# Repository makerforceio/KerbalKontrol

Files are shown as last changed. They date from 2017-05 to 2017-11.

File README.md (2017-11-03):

# KerbalKontrol
Kerbal Space Program is a popular space simulator game which we at MakerForce been enjoying for a while. So, we decided
to just go build an arcade like console for it. This project was fortunate enough to be featured on [Hackaday](), and you
can check out the original blog post [here](https://makerforce.io/the-ksp-command-station-2/).

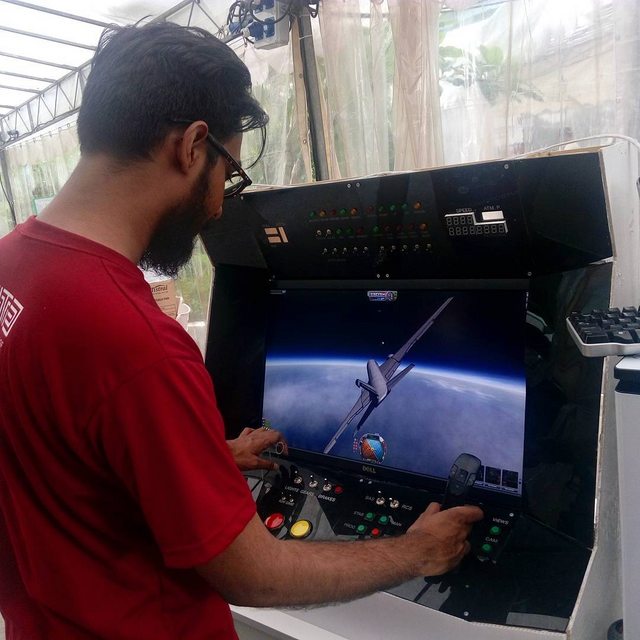
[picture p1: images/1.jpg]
KerbalKontrol station


# Implementation
This control station is based fully upon the ATMEGA328 as its primary MCU. It is powered by 2 custom designed PCBs - the IO-Board and the Main-Board. The IO-Board is connected to each panel and contains a single MCU + shift registers. All of the IO-Boards are wired to the Main-Board using RJ45 conns and ethernet cables. The communication bus within is currently I2C but we want to switch to D-I2C in the future. All of the IO-Boards are configured as I2C Slaves and the Main-Board is the single master.

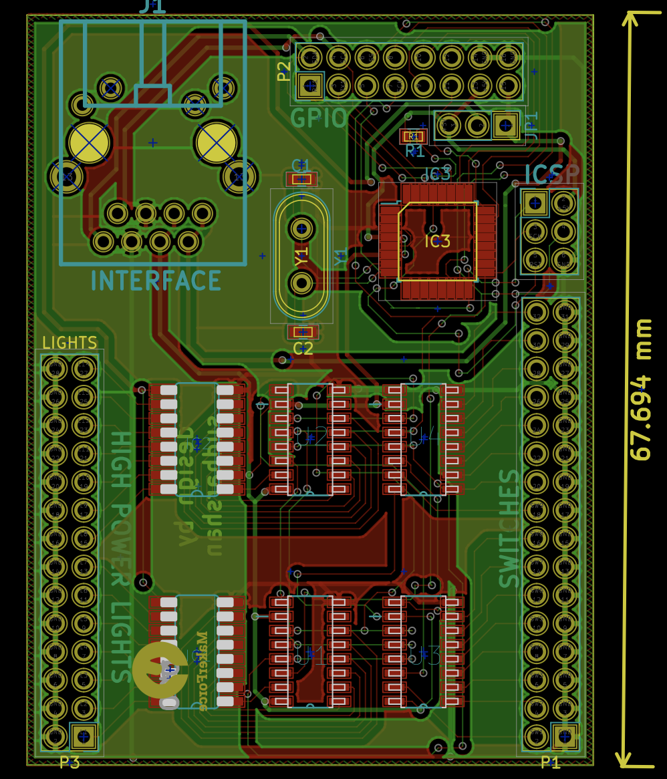
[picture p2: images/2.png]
IO-Board


The internal switches, lights are wired up to the boards through the header connectors visible on the IO-Board.

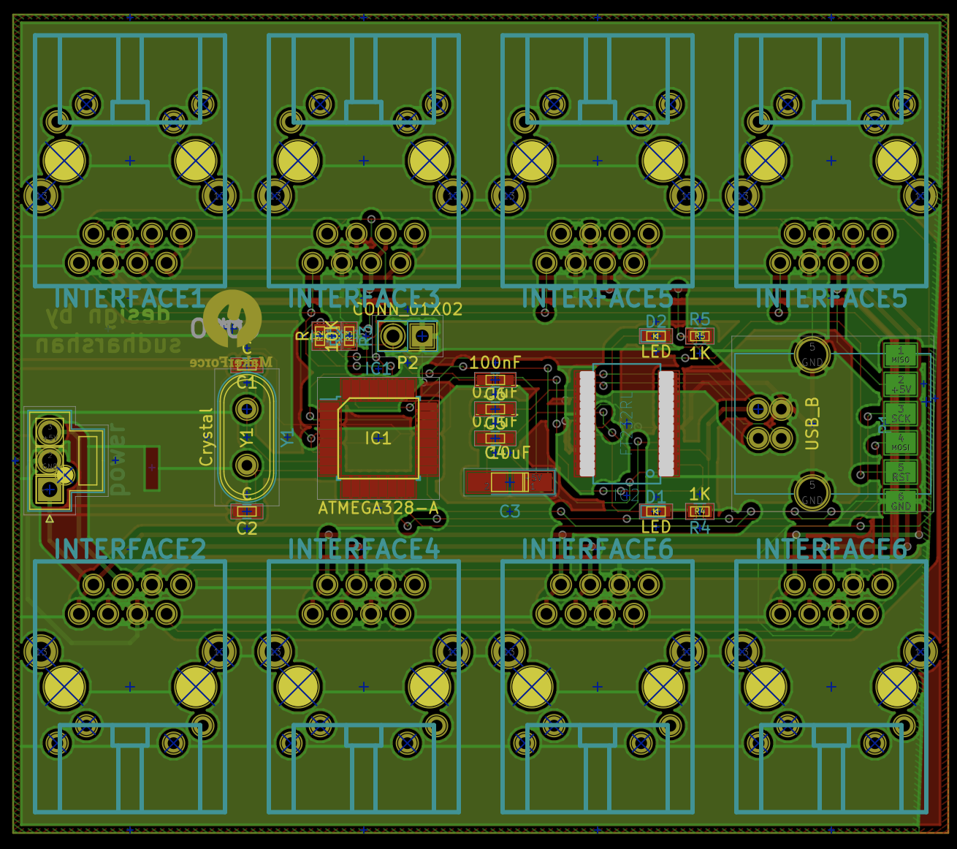
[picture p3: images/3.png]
Main-Board


# Software
Everything is programmed using avr-libc with no external libraries. 

## Compile from source
To compile from source for the IO-Board and Main-Board, follow the steps below.

```
git clone https://www.github.com/solderneer/KerbalKontrol
cd code/io-board
make
```

```
git clone https://www.github.com/solderneer/KerbalKontrol
cd code/main-board
make
```
The directory can simply be cleaned with this command.

```
make clean
```

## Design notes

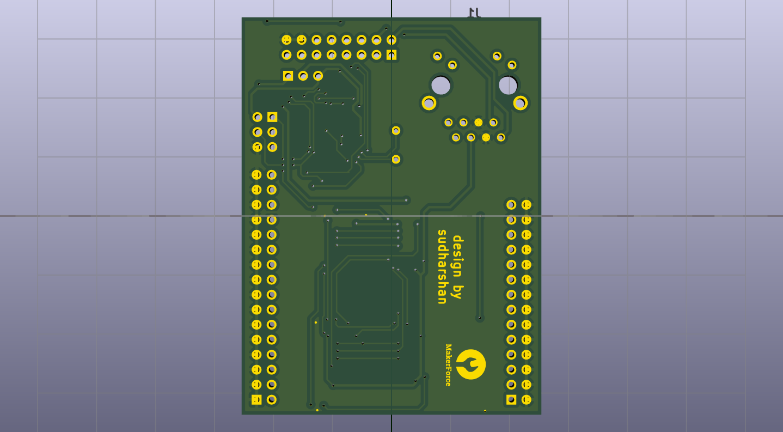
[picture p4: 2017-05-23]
electronics/renders/io-board.back.png

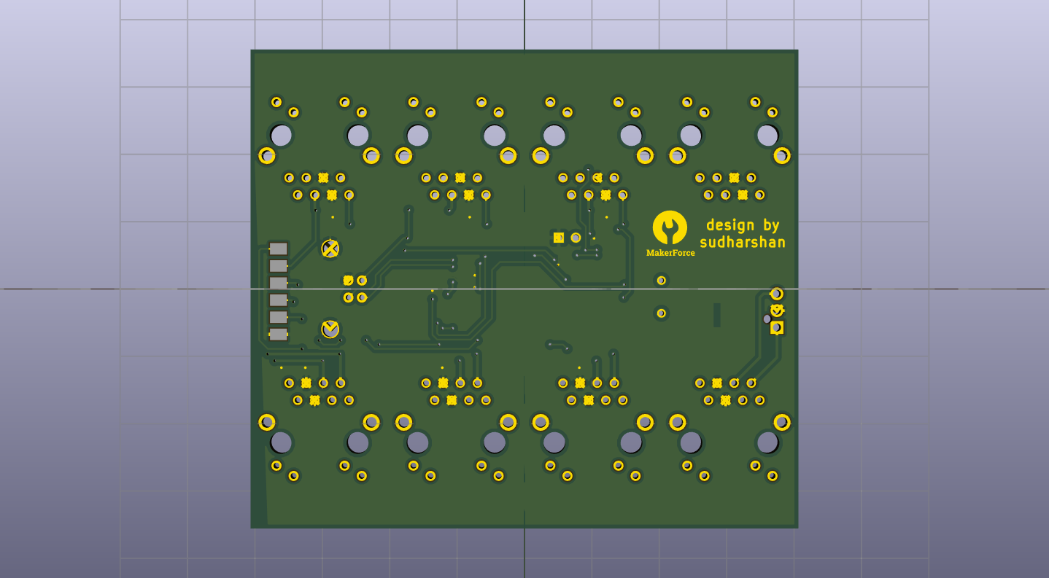
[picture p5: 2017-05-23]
electronics/renders/main-board.back.png

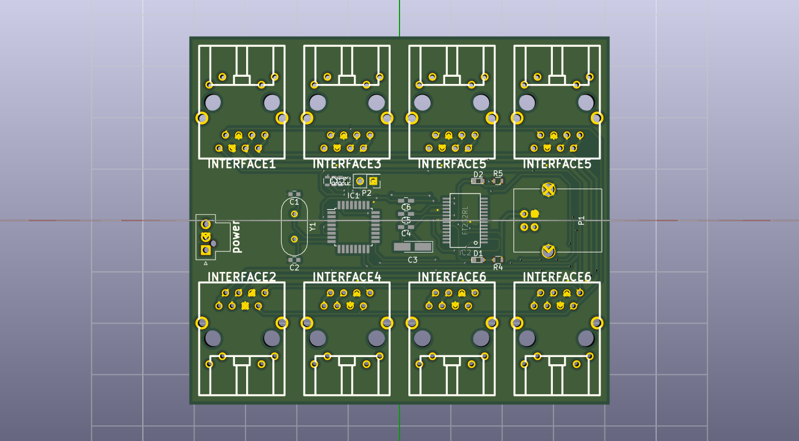
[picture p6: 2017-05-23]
electronics/renders/main-board.png

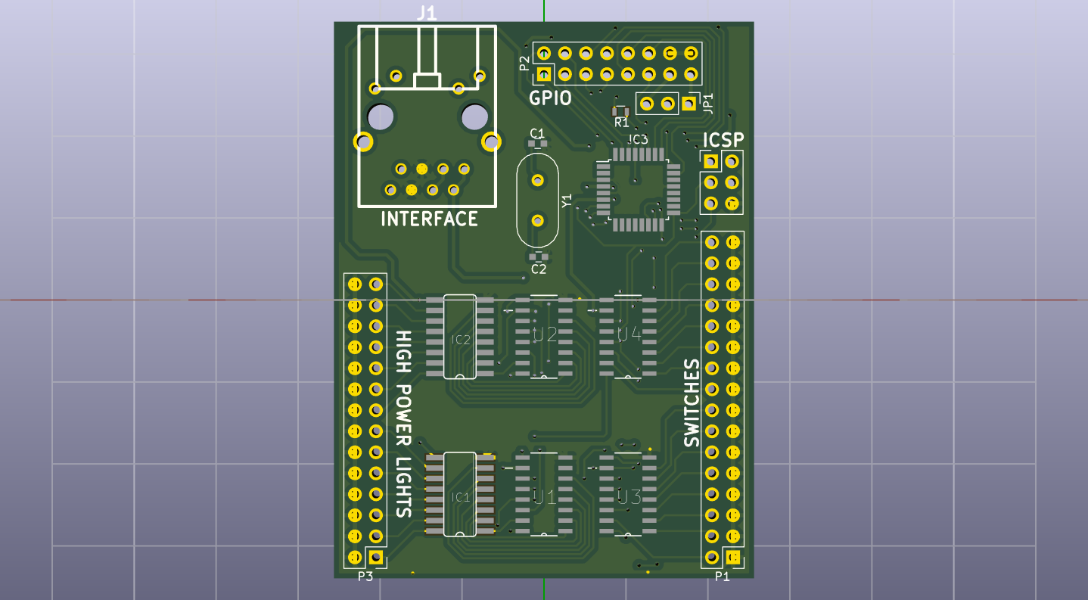
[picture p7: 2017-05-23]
electronics/renders/io-board.png

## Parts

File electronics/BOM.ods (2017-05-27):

IO-Board
Part Name | Part Cost | Quantity | Digikey Link | Digikey Part No. | Part Description
74HC595D |  | 4 | https://www.digikey.sg/product-detail/en/nexperia-usa-inc/74HC595D,118/1727-2821-1-ND/763394 | 1727-2821-1-ND | 5V Shift register with latching outputs
ULN2004A |  | 2 | https://www.digikey.sg/product-detail/en/stmicroelectronics/ULN2004D1013TR/497-2347-1-ND/599188 | 497-2347-1-ND | Source/Sink Transistor array
ATMEGA 328-P |  | 1 | https://www.digikey.sg/product-detail/en/microchip-technology/ATMEGA328P-AUR/ATMEGA328P-AURCT-ND/3789455 | ATMEGA328P-AURCT-ND | 8-bit AVR Microcontroller
RJ45 conn |  | 1 | https://www.digikey.sg/product-detail/en/wiznet/RB1-125BAG1A/1278-1011-ND/3829637 | 1278-1011-ND | Interface connector for I2C (TH)
Y1 |  | 1 | https://www.digikey.sg/product-detail/en/ecs-inc/ECS-160-20-1X/X1033-ND/827525 | X1033-ND | 16Mhz crystal oscillator (HC49)
R1 |  | 1 | https://www.digikey.sg/product-detail/en/yageo/RC0603JR-0710KL/311-10KGRCT-ND/729647 | 311-10KGRCT-ND | 10k resistor (0603 SMD)
C1,C2 |  | 2 | https://www.digikey.sg/product-detail/en/kemet/C0603C270F5GACTU/399-7888-1-ND/3471611 | 399-7888-1-ND | 27uF ceramic capacitor (0603 SMD)
Main-Board
Part Name | Part Cost | Quantity |  | Digikey Part No. | Part Description
ATMEGA 328-P |  | 1 | https://www.digikey.sg/product-detail/en/microchip-technology/ATMEGA328P-AUR/ATMEGA328P-AURCT-ND/3789455 | ATMEGA328P-AURCT-ND | 8-bit AVR Microcontroller
C1,C2 |  | 2 | https://www.digikey.sg/product-detail/en/kemet/C0603C270F5GACTU/399-7888-1-ND/3471611 | 399-7888-1-ND | 27uF ceramic capacitor (0603 SMD)
C3 |  | 1 |  |  | 10uF ceramic capacitor (0603 SMD)
C4,C5,C6 |  | 2 | https://www.digikey.sg/product-detail/en/murata-electronics-north-america/GRM188R71C104KA01D/490-1532-2-ND/587060 | 490-1532-2-ND | 0.1uF ceramic capacitor (0603 SMD)
USB_B conn |  | 1 | https://www.digikey.sg/product-detail/en/on-shore-technology-inc/USB-B1HSW6/ED2982-ND/2677743 | ED2982-ND | USB type B connector (TH)
D1 |  | 1 | https://www.digikey.sg/product-detail/en/lite-on-inc/LTST-C191KSKT/160-1448-1-ND/386838 | 160-1448-1-ND | Yellow LED (0603 SMD)
D2 |  | 1 | https://www.digikey.sg/product-detail/en/lite-on-inc/LTST-C193TBKT-5A/160-1827-1-ND/2355044 | 160-1827-1-ND | Blue LED (0603 SMD)
R1,R2 |  | 2 | https://www.digikey.sg/product-detail/en/yageo/RC0603JR-071KL/311-1.0KGRTR-ND/726677 | 311-1.0KGRTR-ND | 1k I2C pullup resistors (0603 SMD)
R3 |  | 1 | https://www.digikey.sg/product-detail/en/yageo/RC0603JR-0710KL/311-10KGRCT-ND/729647 | 311-10KGRCT-ND | 10k reset pullup (0603 SMD)
R4,R5 |  | 2 | https://www.digikey.sg/product-detail/en/yageo/RC0603JR-071KL/311-1.0KGRTR-ND/726677 | 311-1.0KGRTR-ND | 1k LED current limiters (0603 SMD)
RJ45 conn |  | 8 | https://www.digikey.sg/product-detail/en/wiznet/RB1-125BAG1A/1278-1011-ND/3829637 | 1278-1011-ND | Interface connector for I2C (TH)
MOLEX nano |  | 1 | https://www.digikey.sg/product-detail/en/molex-llc/1053091203/WM14966-ND/6131608 | WM14966-ND | High current power

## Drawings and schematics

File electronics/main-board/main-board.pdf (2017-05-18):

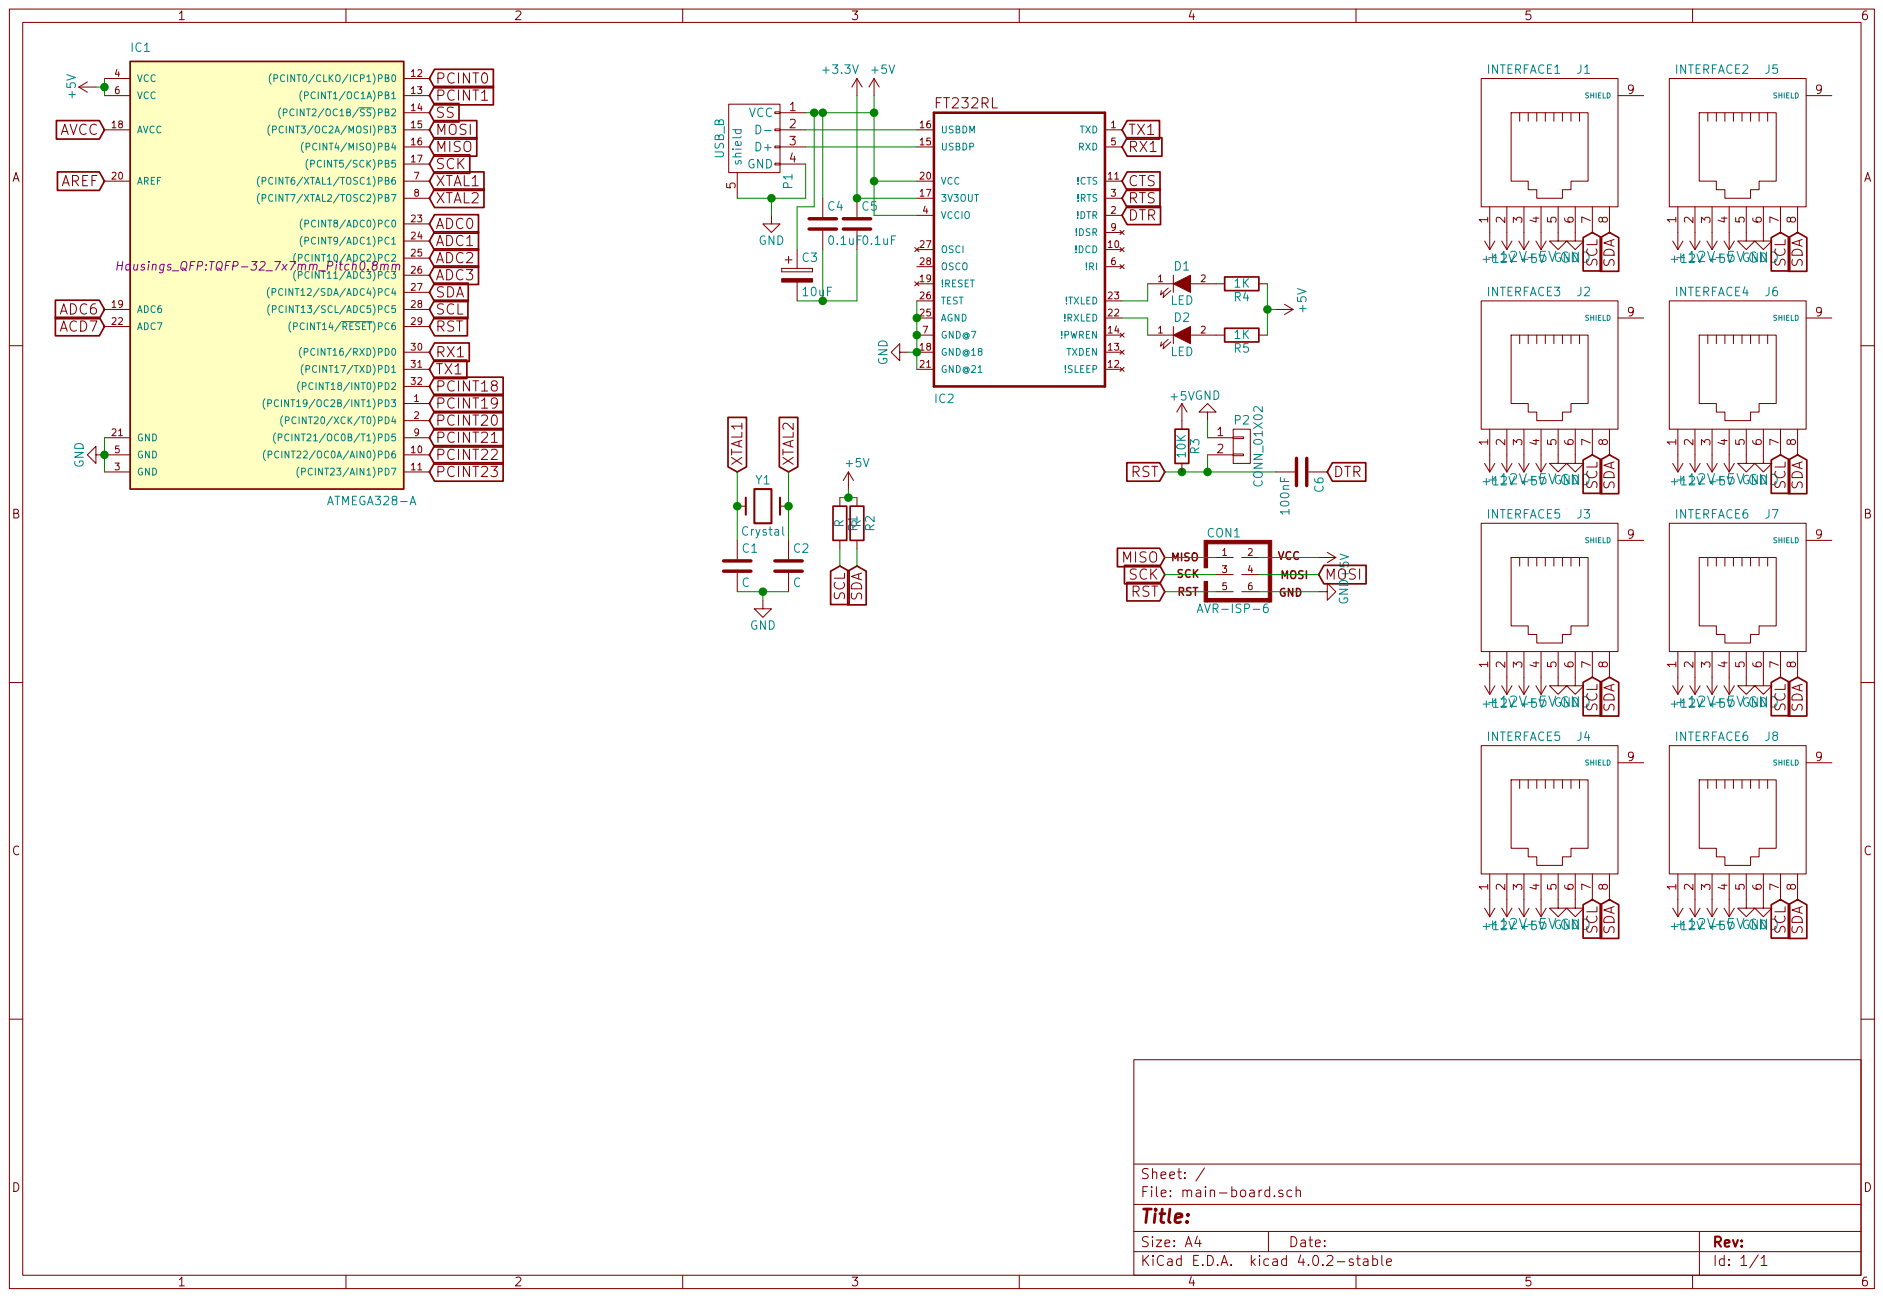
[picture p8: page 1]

Id: 1/1 Title: File: main-board.sch Sheet: /

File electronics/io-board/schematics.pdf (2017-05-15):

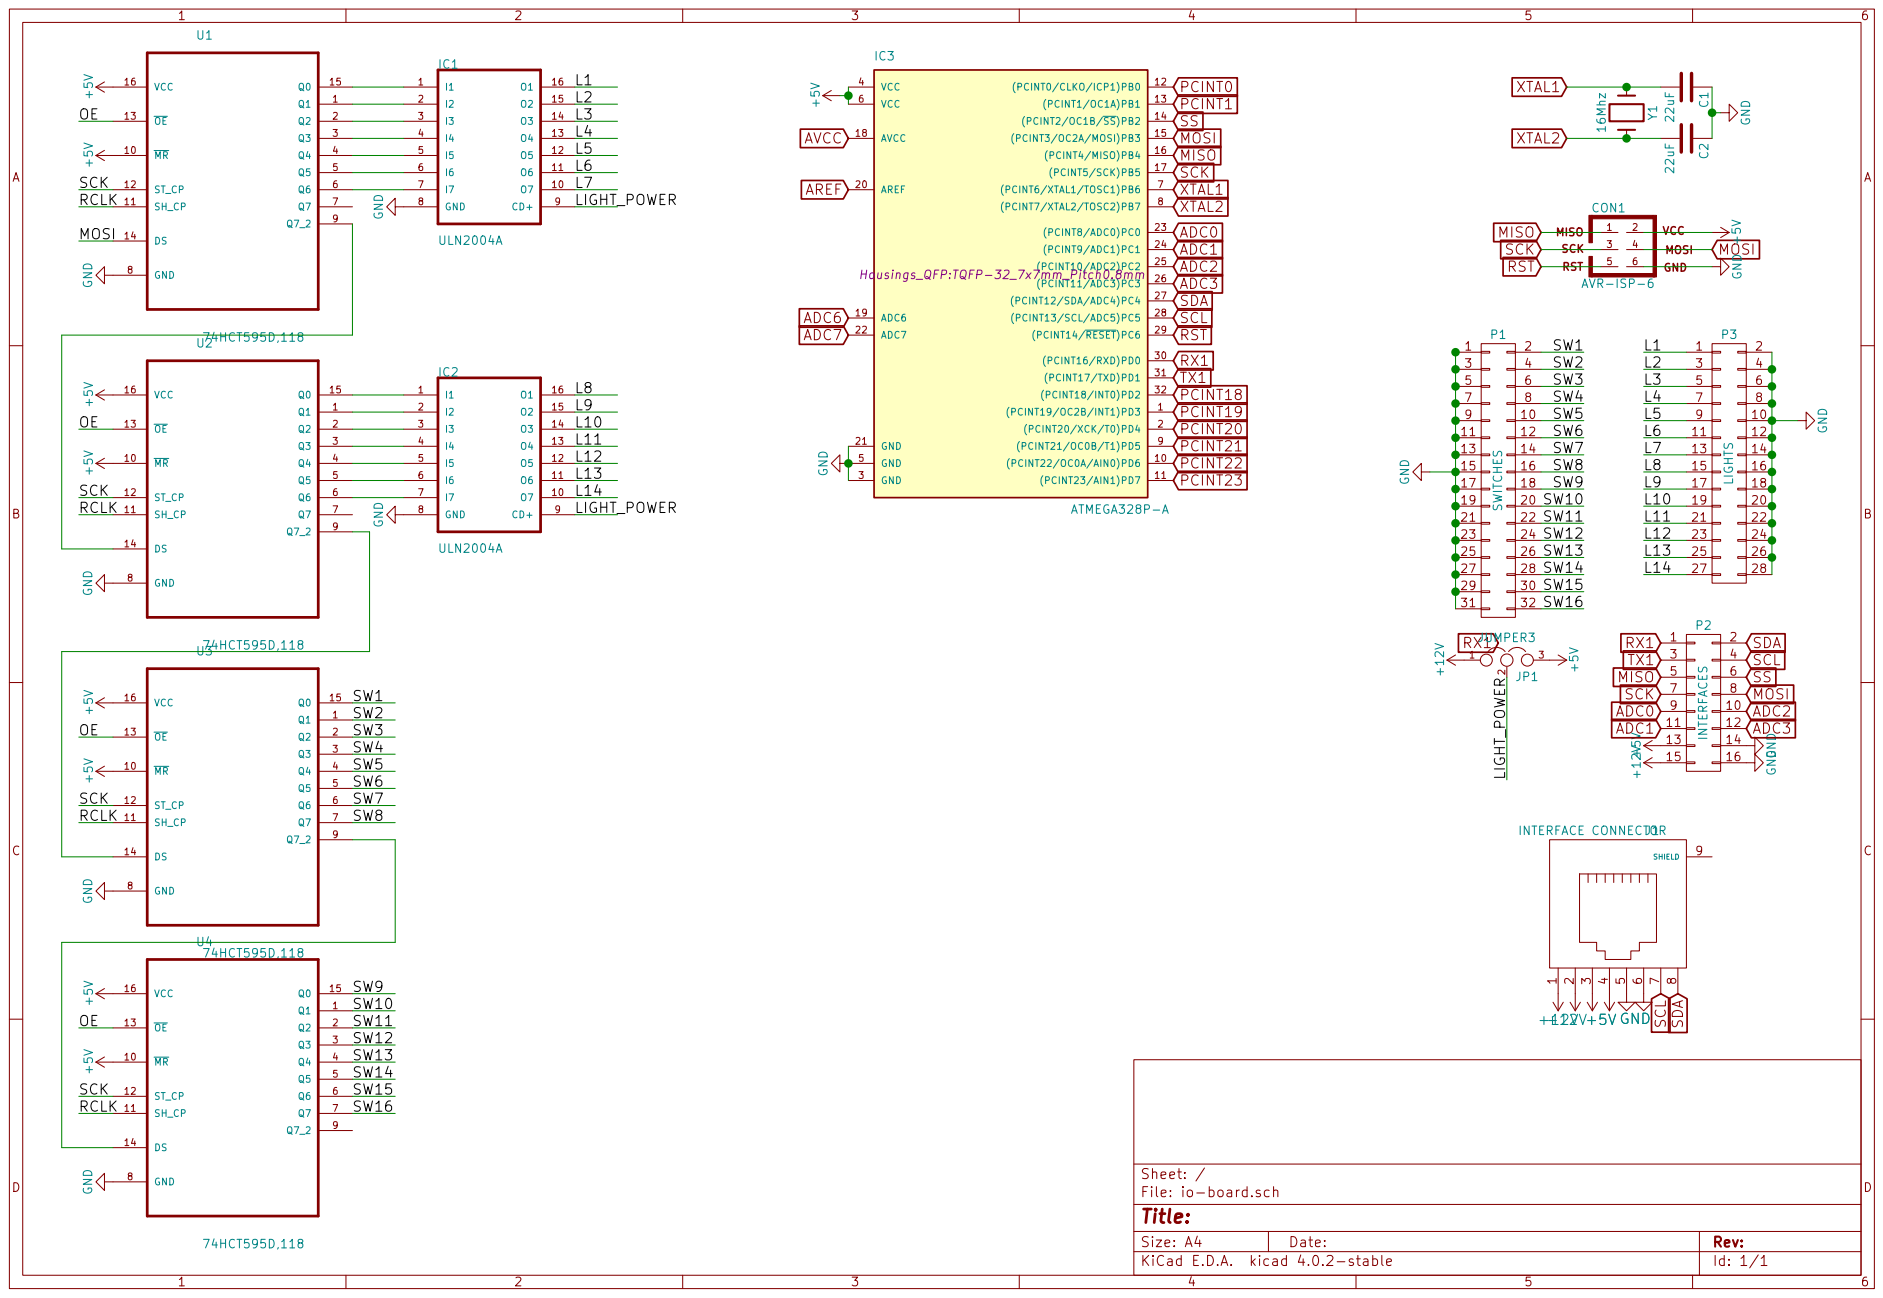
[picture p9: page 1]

I4 4 | L4
I5 5 | L5
I6 6 | L6

29 P1SWITCHES | | SW5 | L5 | 12

SW2 | L2
SW3 | L3
SW4 | L4

11 | | 12 SW6 | L6 11
13 | | 14 SW7 | L7 13 | 14
15 17 | | SW8 16 | L8 15 | 16

I4 4 | L11
I5 5 | L12

19 | | SW10 20 | | 20
21 | | 22 SW11 | 21 | 22
23 | | 24 SW12 | L12 23 | 24
25 | | SW13 26 | L13 25 | 26
27 | | 28 SW14 | 27 | 28

Id: 1/1 Title: File: io-board.sch Sheet: /

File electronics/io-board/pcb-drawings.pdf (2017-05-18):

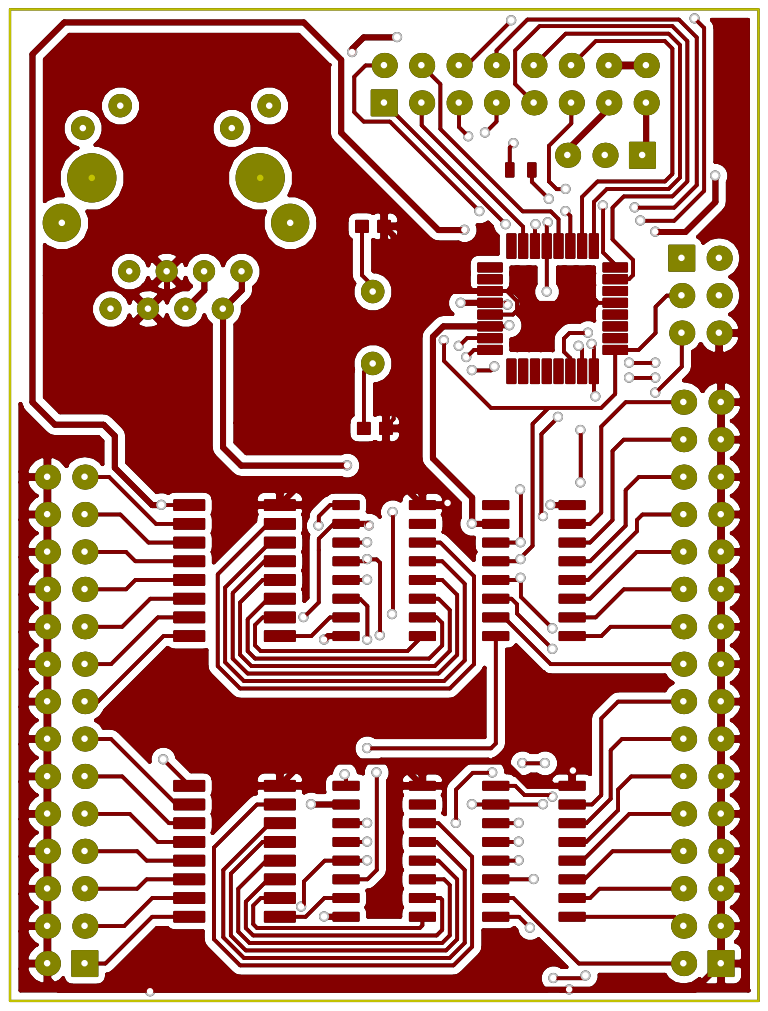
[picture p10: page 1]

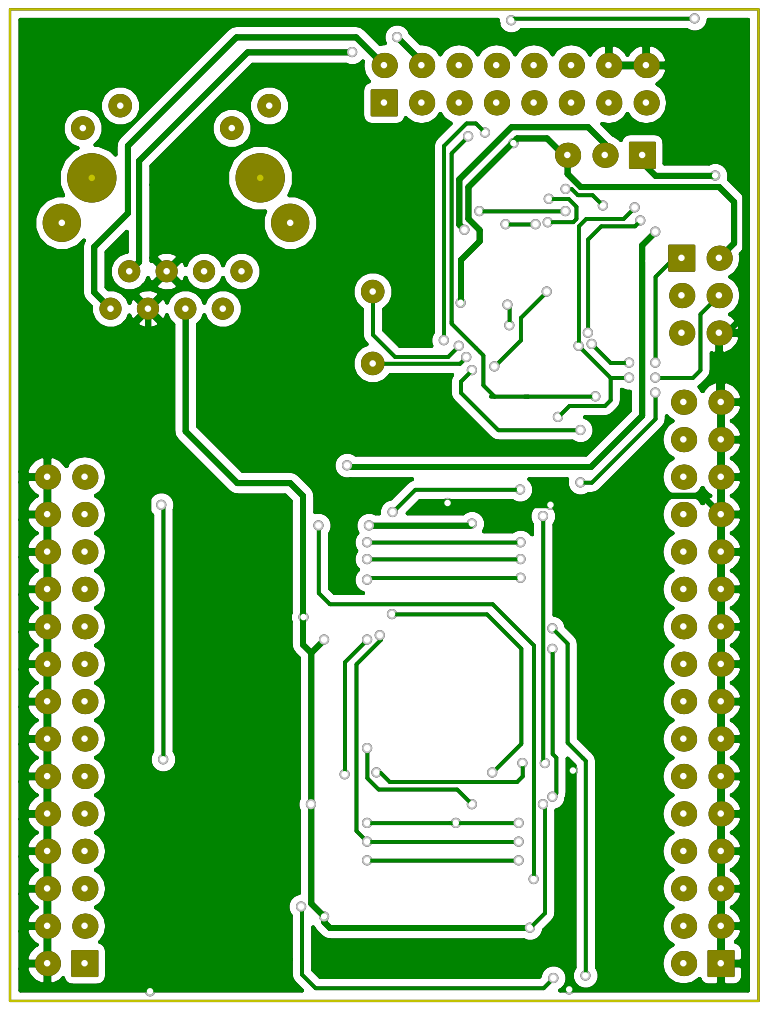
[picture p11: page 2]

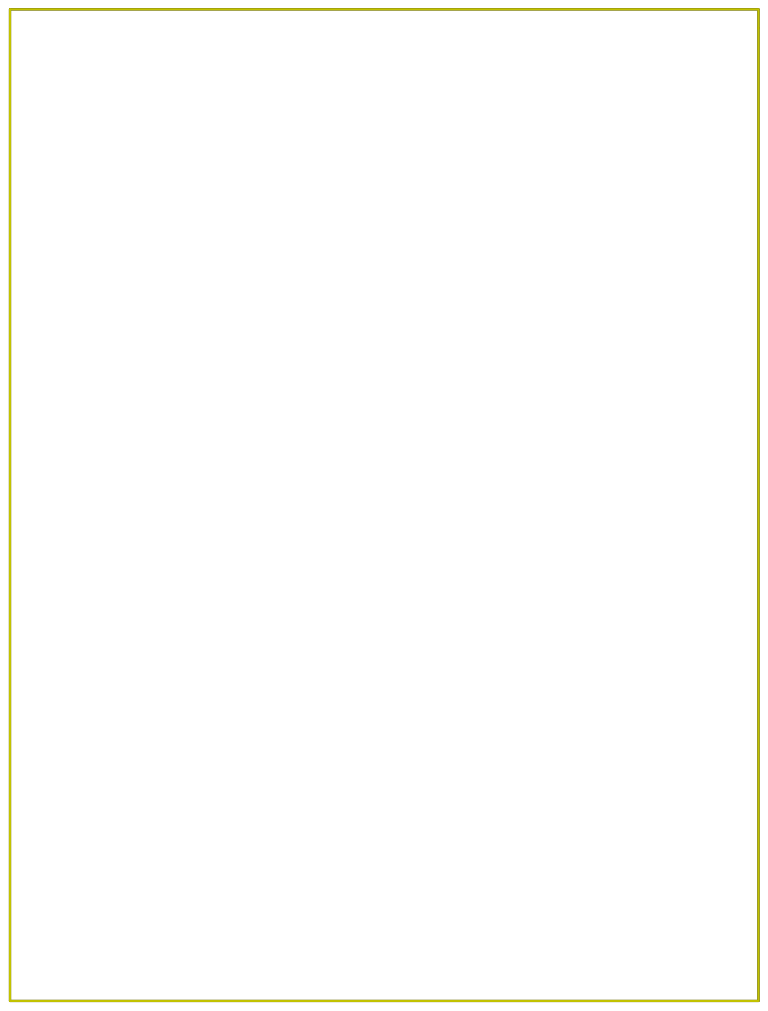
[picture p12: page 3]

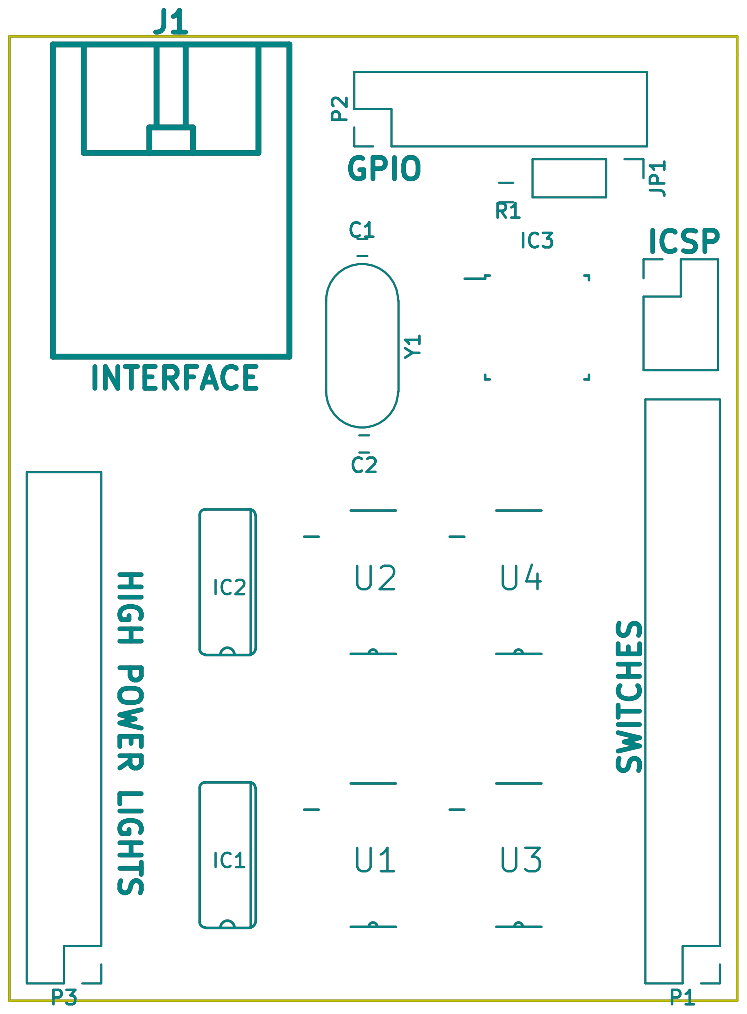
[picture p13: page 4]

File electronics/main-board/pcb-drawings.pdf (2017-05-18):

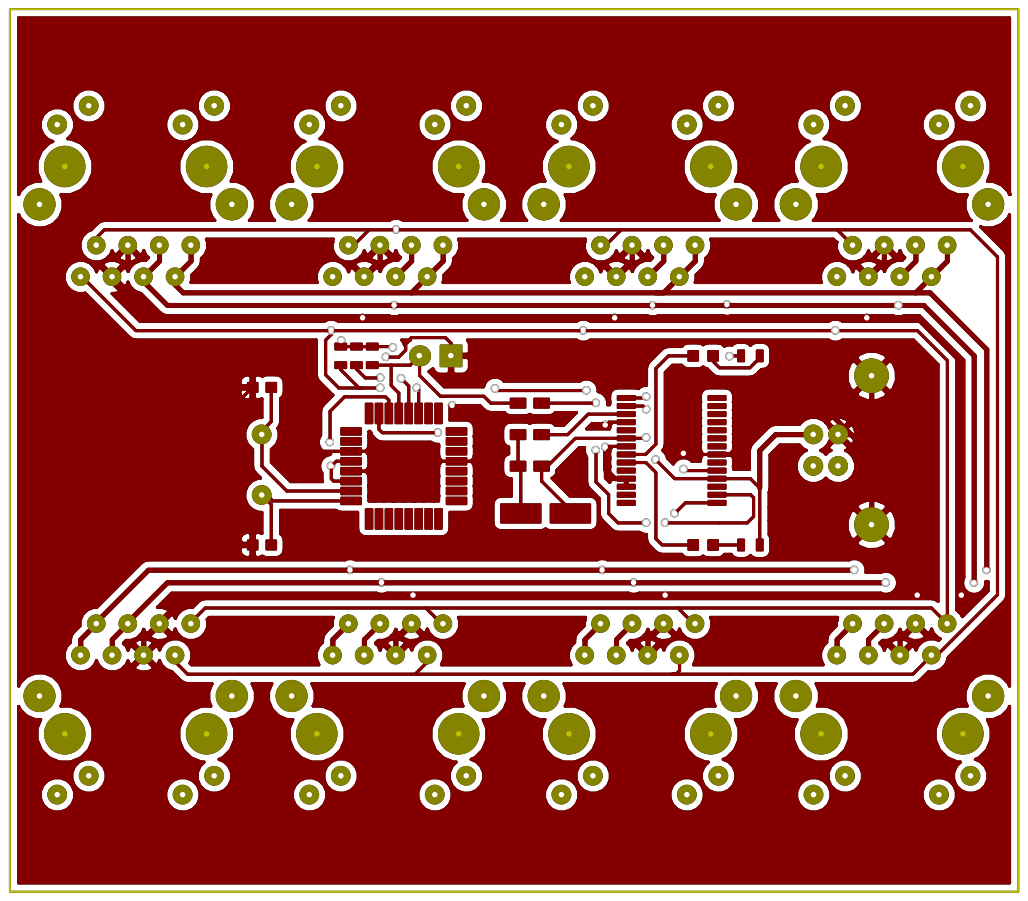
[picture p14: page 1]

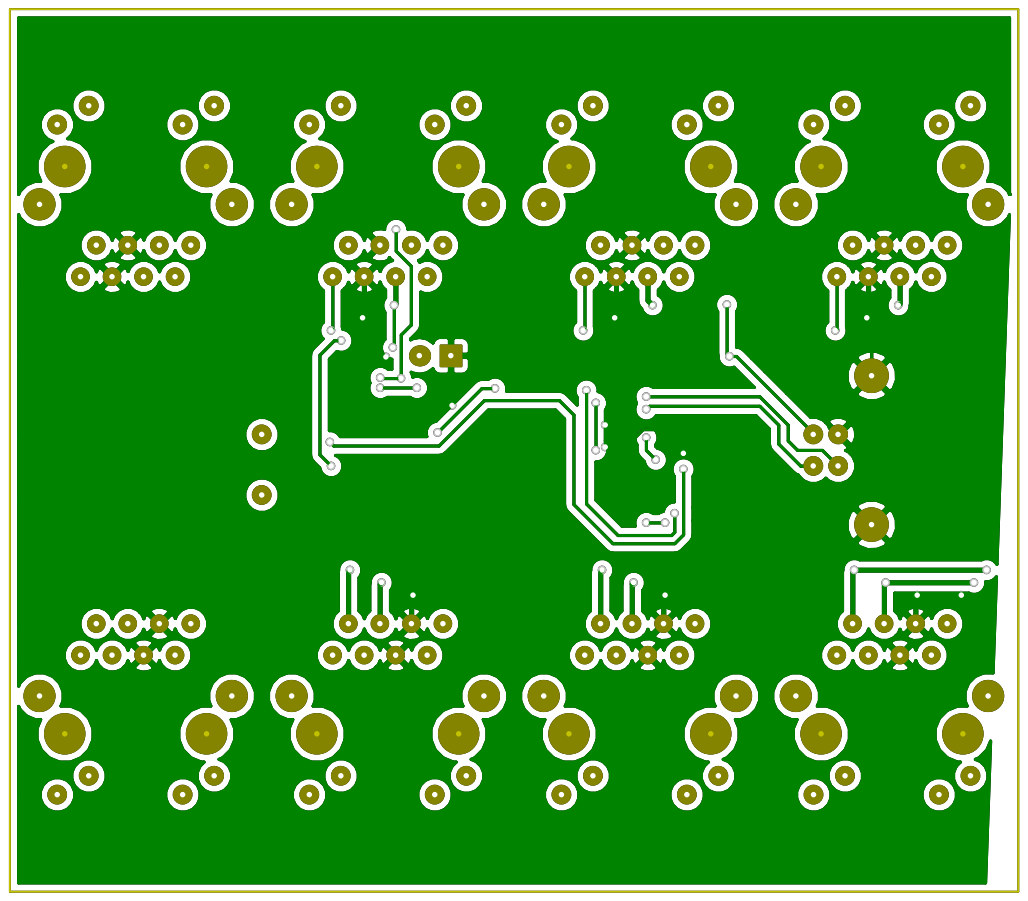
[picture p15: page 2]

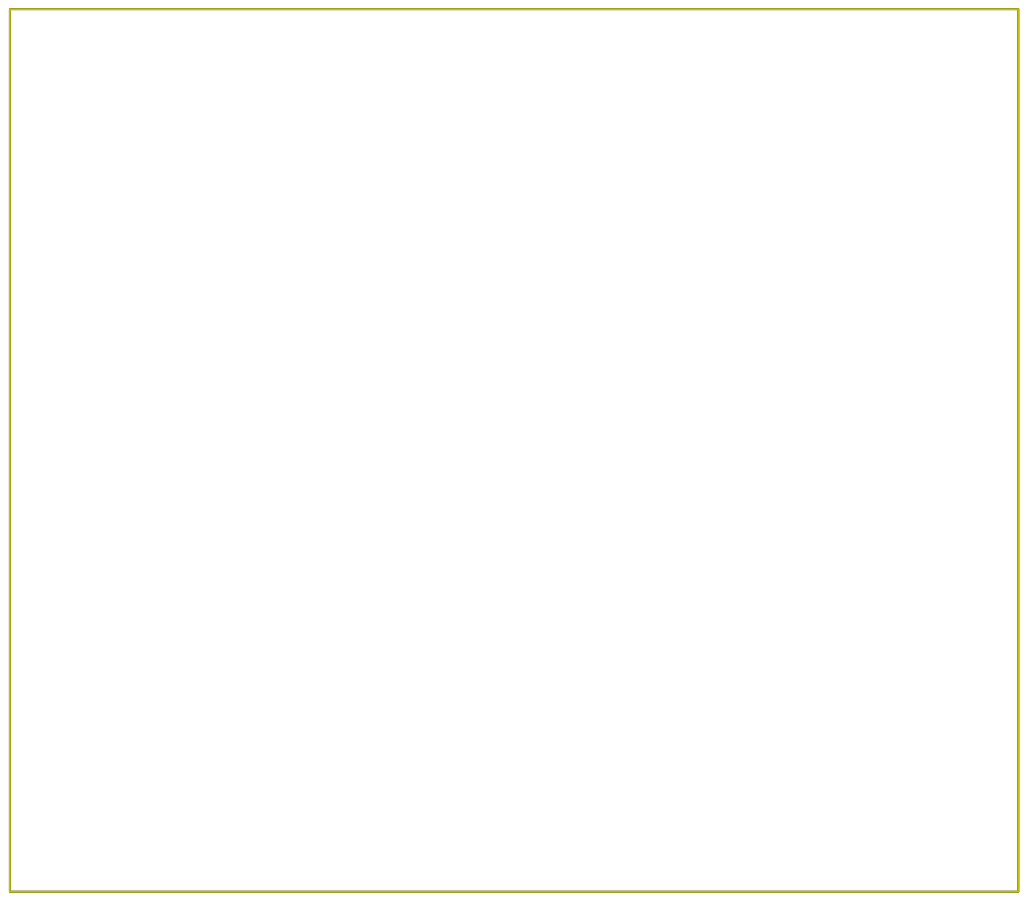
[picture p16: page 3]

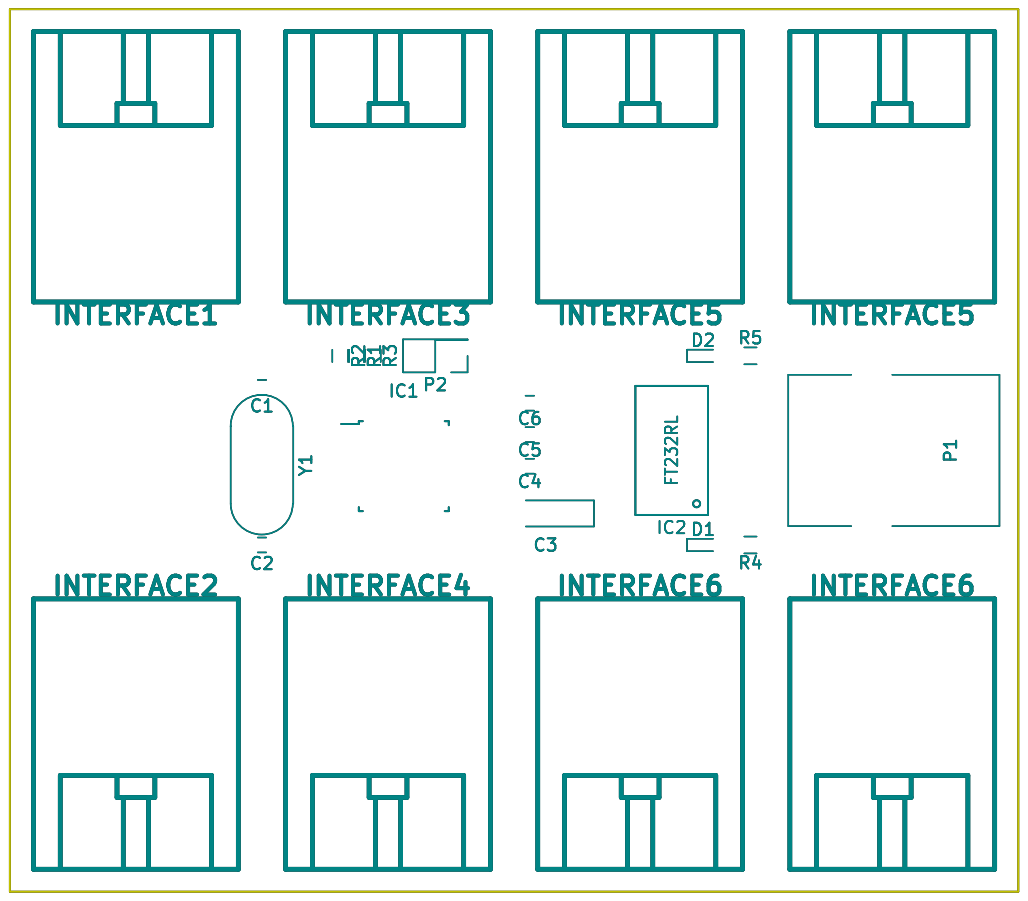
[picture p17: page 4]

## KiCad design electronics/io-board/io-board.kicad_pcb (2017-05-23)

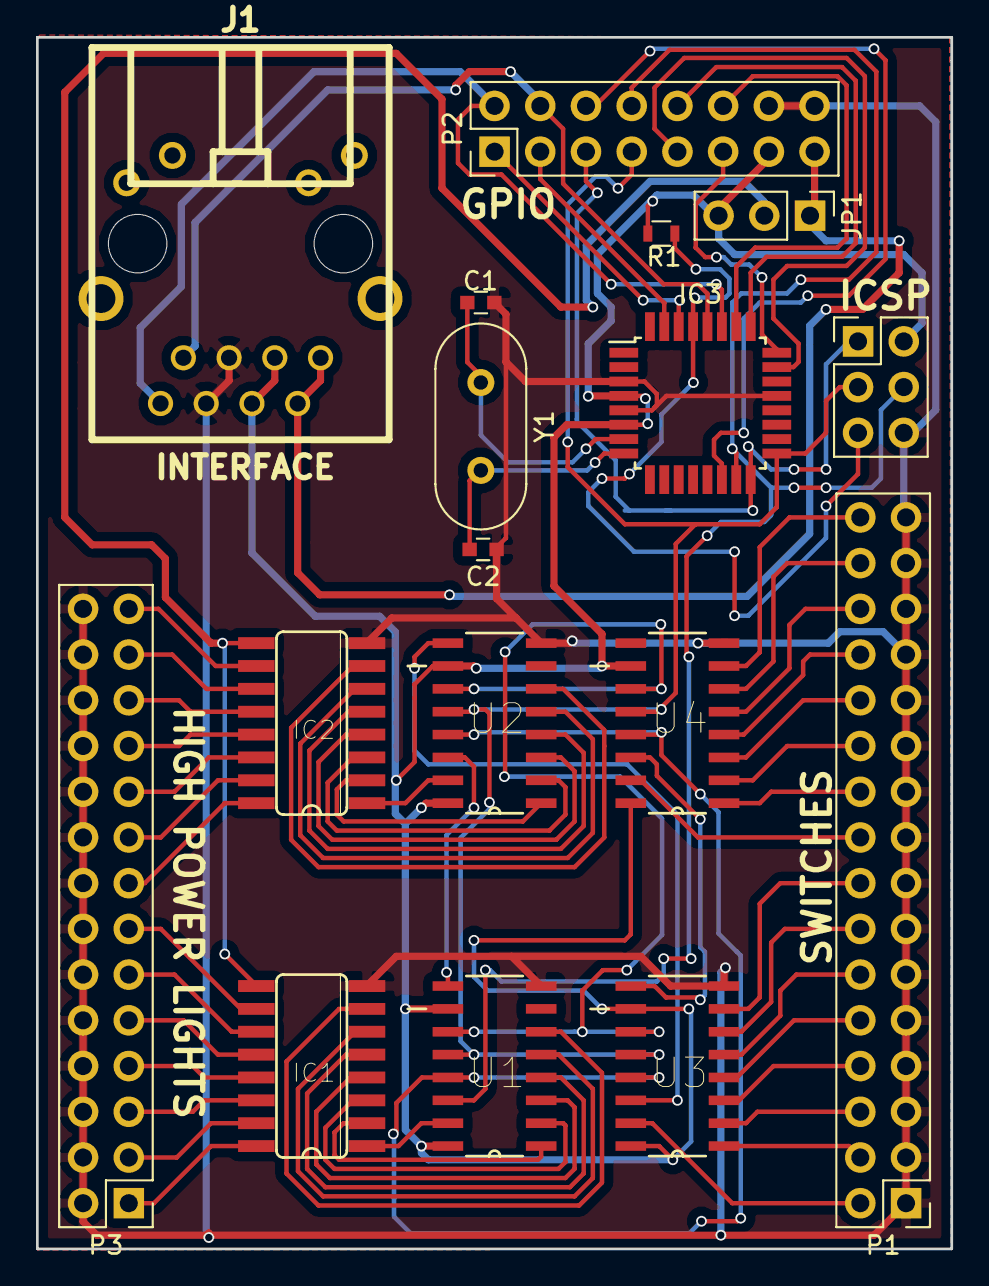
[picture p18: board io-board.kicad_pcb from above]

Board: 2 copper layers, 50.8 x 67.3 mm, 16 parts (0 on the bottom side), 68 nets.

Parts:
C1, C2: C_0603
IC1, IC2: SO16
IC3: TQFP-32_7x7mm_Pitch0.8mm
J1: INTERFACE; rj45-wiznet-rb1-125bag1a
JP1: Pin_Header_Straight_1x03_Pitch2.54mm
P1: Pin_Header_Straight_2x16_Pitch2.54mm
P2: Pin_Header_Straight_2x08_Pitch2.54mm
P3: LIGHTS; Pin_Header_Straight_2x14_Pitch2.54mm
R1: R_0603
U1, U2, U3, U4: SOIC127P600X175-16N
Y1: Crystal_HC49-4H_Vertical

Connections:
+5V: IC3.4, IC3.6, J1.3, J1.4, JP1.3, P2.13, R1.1, U1.10, U1.16, U2.10, U2.16, U3.10, U3.16, U4.10, U4.16
+12V: J1.1, J1.2, JP1.1, P2.15
/L1: IC1.16, P3.1
/L2: IC1.15, P3.3
/L3: IC1.14, P3.5
/L4: IC1.13, P3.7
/L5: IC1.12, P3.9
/L6: IC1.11, P3.11
/L7: IC1.10, P3.13
/L8: IC2.16, P3.15
/L9: IC2.15, P3.17
/L10: IC2.14, P3.19
/L11: IC2.13, P3.21
/L12: IC2.12, P3.23
/L13: IC2.11, P3.25
/L14: IC2.10, P3.27
/LIGHT_POWER: IC1.9, IC2.9, JP1.2
/OE: U1.13, U2.13, U3.13, U4.13
/RCLK: U1.11, U2.11, U3.11, U4.11
/SW1: P1.2, U3.15
/SW2: P1.4, U3.1
/SW3: P1.6, U3.2
/SW4: P1.8, U3.3
/SW5: P1.10, U3.4
/SW6: P1.12, U3.5
/SW7: P1.14, U3.6
/SW8: P1.16, U3.7
/SW9: P1.18, U4.15
/SW10: P1.20, U4.1
/SW11: P1.22, U4.2
/SW12: P1.24, U4.3
/SW13: P1.26, U4.4
/SW14: P1.28, U4.5
/SW15: P1.30, U4.6
/SW16: P1.32, U4.7
ADC0: IC3.23, P2.9
ADC1: IC3.24, P2.11
ADC2: IC3.25, P2.10
ADC3: IC3.26, P2.12
GND: C1.1, C2.1, IC1.8, IC2.8, IC3.3, IC3.5, IC3.21, J1.5, J1.6, P1.1, P1.3, P1.5, P1.7, P1.9, P1.11, P1.13, P1.15, P1.17, P1.19, P1.21, P1.23, P1.25, P1.27, P1.29, P1.31, P2.14, P2.16, P3.2, P3.4, P3.6, P3.8, P3.10, P3.12, P3.14, P3.16, P3.18, P3.20, P3.22, P3.24, P3.26, P3.28, U1.8, U2.8, U3.8, U4.8
MISO: IC3.16, P2.5
MOSI: IC3.15, P2.8, U1.14
unnamed: IC1.1, U1.15
unnamed: IC1.2, U1.1
unnamed: IC1.3, U1.2
unnamed: IC1.4, U1.3
unnamed: IC1.5, U1.4
unnamed: IC1.6, U1.5
unnamed: IC1.7, U1.6
unnamed: IC2.1, U2.15
unnamed: IC2.2, U2.1
unnamed: IC2.3, U2.2
unnamed: IC2.4, U2.3
unnamed: IC2.5, U2.4
unnamed: IC2.6, U2.5
unnamed: IC2.7, U2.6
unnamed: U1.9, U2.14
unnamed: U2.9, U3.14
unnamed: U3.9, U4.14
RST: IC3.29, R1.2
RX1: IC3.30, P2.1
SCK: IC3.17, P2.7, U1.12, U2.12, U3.12, U4.12
SCL: IC3.28, J1.7, P2.4
SDA: IC3.27, J1.8, P2.2
SS: IC3.14, P2.6
TX1: IC3.31, P2.3
XTAL1: C1.2, IC3.7, Y1.1
XTAL2: C2.2, IC3.8, Y1.2

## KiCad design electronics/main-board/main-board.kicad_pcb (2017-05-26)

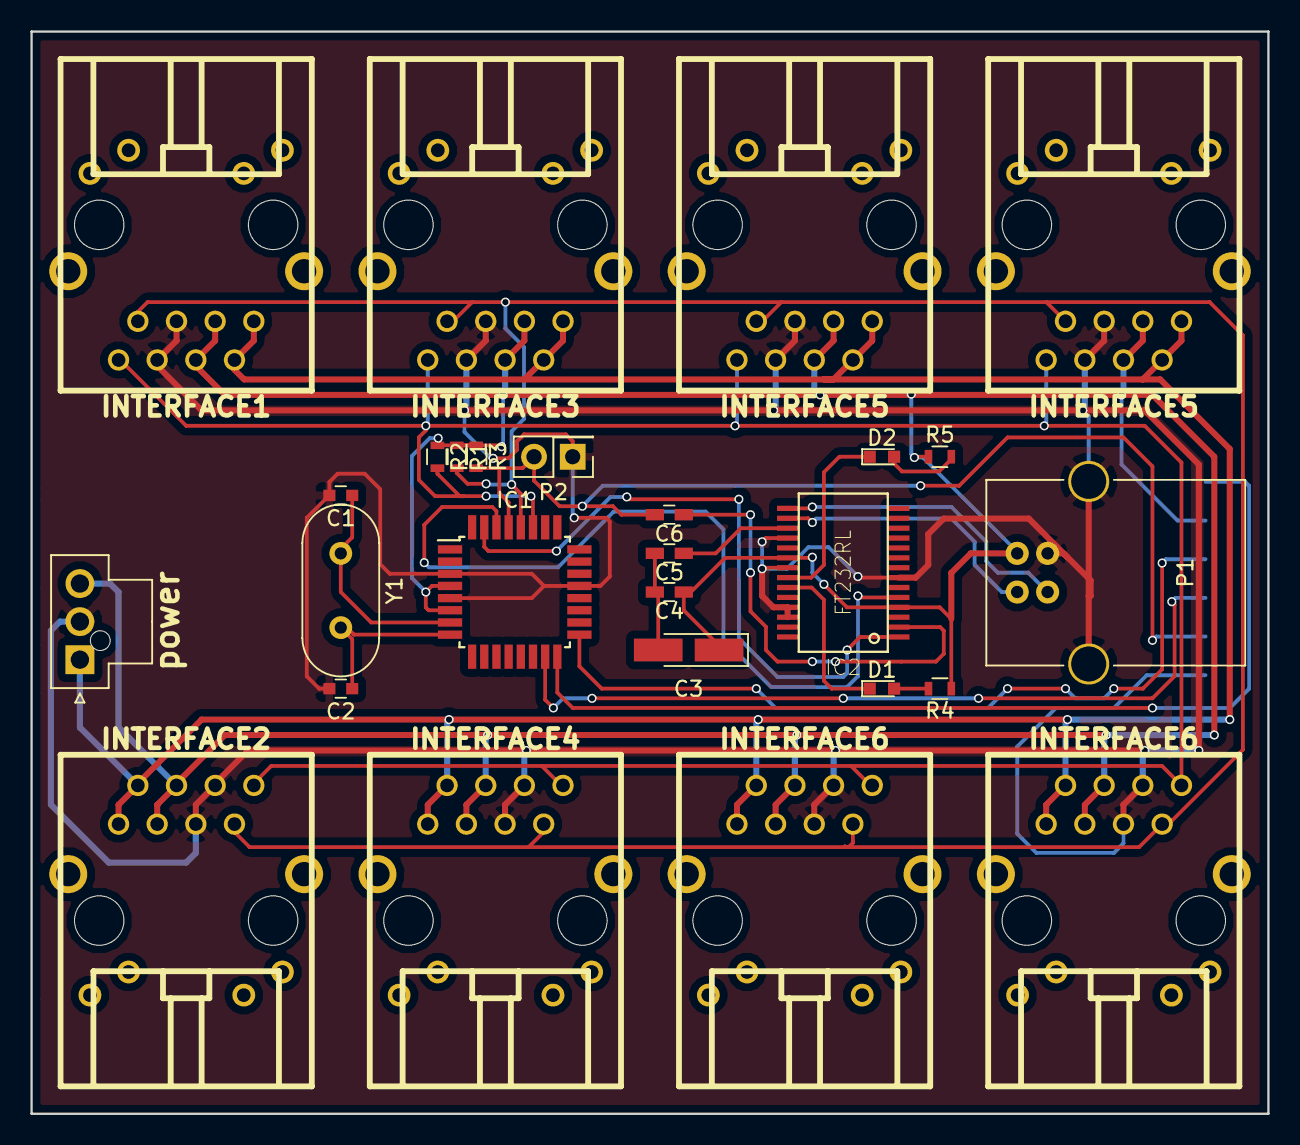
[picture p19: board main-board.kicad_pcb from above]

Board: 2 copper layers, 81.3 x 71.1 mm, 18 parts (0 on the bottom side), 18 nets.

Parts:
C1, C2: C; C_0603
C3: 10uF; CP_Tantalum_Case-S_EIA-3216-12_Hand
C4, C5: 0.1uF; C_0603_HandSoldering
C6: 100nF; C_0603_HandSoldering
D1, D2: LED; LED_0603
IC1: ATMEGA328-A; TQFP-32_7x7mm_Pitch0.8mm
IC2: FT232RL; SSOP28-LD
P1: USB_B
P2: CONN_01X02; Pin_Header_Straight_2x01_Pitch2.54mm
R1, R2: R; R_0603
R3: 10K; R_0603
R4, R5: 1K; R_0603
Y1: Crystal; Crystal_HC49-U_Vertical

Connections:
+3V3: C5.1, IC2.17
+5V: C3.1, C4.1, IC1.4, IC1.6, IC2.4, IC2.20, P1.1, R1.1, R2.1, R3.1, R4.1, R5.1
DTR: C6.1, IC2.2
GND: C1.2, C2.2, IC1.3, IC1.5, IC1.21, IC2.7, IC2.18, IC2.21, IC2.25, IC2.26, P1.4, P1.5, P2.1
unnamed: C3.2, C4.2, C5.2
unnamed: D1.1, IC2.23
unnamed: D1.2, R4.2
unnamed: D2.1, IC2.22
unnamed: D2.2, R5.2
unnamed: IC2.15, P1.3
unnamed: IC2.16, P1.2
RST: C6.2, IC1.29, P2.2, R3.2
RX1: IC1.30, IC2.5
SCL: IC1.28, R1.2
SDA: IC1.27, R2.2
TX1: IC1.31, IC2.1
XTAL1: C1.1, IC1.7, Y1.1
XTAL2: C2.1, IC1.8, Y1.2

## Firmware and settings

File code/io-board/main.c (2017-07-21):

#ifndef F_CPU
#define F_CPU 16000000UL // 16 MHz clock speed
#endif

#include <avr/io.h>
#include <util/delay.h>
#include "74hc595.h"
#include "switches.h"
#include "i2c.h"

#define I2C_ADDR 0x10

volatile uint8_t data;

port_t selectPort = portnone;
opcode_t opcode = NONE_SELECTED;
uint8_t pinSelect = 0;
uint8_t updateFlag = 0;

void I2C_received(uint8_t received_data)
{
  if(received_data & 0x01)
  {
    //Means first bit is set and is a setup command
    opcode = ((received_data >> 1) & 0x0F); // Next 4 bits are opcode
    selectPort = ((received_data >> 5) & 0x08); //Next 3 bits are port address
    updateFlag = 1;
  }
  else
  {
    //Means first bit
    if(updateFlag == 1)
    {
      //If setup cmd has been received, store data into pinSelect
      pinSelect = (received_data >> 1) & 0x8F;
      updateFlag = 2;
    }
    else; //Ignore data sent
  }
}

void I2C_requested()
{
  if(updateFlag == 1)
  {
    updateFlag = 2;
  }
  else; //Ignore data request
}

void setup()
{
  I2C_setCallbacks(I2C_received, I2C_requested);
  I2C_init(I2C_ADDR);
  Switches_Init();
}

int main()
{
  setup();
  uint16_t switchBuffer;
  // Main program loop
  while(1)
  {
    if(updateFlag == 2)
    {
      cli();
      switch(opcode)
      {
        case NONE_SELECTED:
          updateFlag = 0; //reset state and continue
          break;
        case SWITCH_GET_TOP:
          Switches_Scan(&switchBuffer);
          TWDR = (uint8_t)(switchBuffer >> 8);
          updateFlag = 0;
          break;
        case SWITCH_GET_BOT:
          Switches_Scan(&switchBuffer);
          TWDR = (uint8_t)(switchBuffer >> 8);
          updateFlag = 0;
        case LIGHT_SET:
          Shift_Set(selectPort, pinSelect);
          Shift_Clear(selectPort, ~(pinSelect));
          updateFlag = 0;
          break;
      }
      sei();
    }
  }

  }

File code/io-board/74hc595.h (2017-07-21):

#ifndef SHIFT_H
#define SHIFT_H

#include "io.h"

#include <util/delay.h>

/* Process goes like this
 * (1) Set latch pin LOW
 * (2) Shift out the data over SPI (one byte)
 * (3) Set latch pin LOW
 */

#define pin0 (1 << 0)
#define pin1 (1 << 1)
#define pin2 (1 << 2)
#define pin3 (1 << 3)
#define pin4 (1 << 4)
#define pin5 (1 << 5)
#define pin6 (1 << 6)
#define pin7 (1 << 7)

#define LATCHPIN (1 << 6)
#define OE (1 << 5)
#define CLOCK (1 << 5)
#define DATA (1 << 3)

typedef enum{port0 = 3, port1 = 2, port2 = 1, port3 = 0, portnone = 4} port_t;


void Shift_Init(void);
void Shift_Write(port_t portx, uint8_t pinx, PinState_t pinState);
void Shift_Set(port_t portx, uint8_t pinx);
void Shift_Clear(port_t portx, uint8_t pinx);
void Shift_Toggle(port_t portx, uint8_t pinx);

#endif /* SHIFT_H */

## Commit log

2017-05-15 started work on the schematic
    [kerbalkontrol.kicad_pcb, kerbalkontrol.sch]
2017-05-15 finished schematics for io-board
    [io-board.kicad_pcb, io-board.sch, kerbalkontrol.sch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]
2017-05-15 started working on the main-board
    [_saved_main-board.sch, io-board.sch]
2017-05-15 finished the schematics for main-board
    [_saved_main-board.sch, main-board.sch]
2017-05-15 started routing io-board
    [io-board.kicad_pcb, io-board.sch]
2017-05-15 finished routing io-board
    [_saved_io-board.sch, io-board.kicad_pcb]
2017-05-15 added PDF for schematics & pcb layout
    [_saved_io-board.sch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]
2017-05-16 fixed some routing
    [io-board.kicad_pcb, io-board.sch, main-board.sch]
2017-05-16 started routing main-board
    [io-board.kicad_pcb, io-board.sch, main-board.kicad_pcb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]
2017-05-16 finidhed routing the main-board
    [main-board.kicad_pcb]
2017-05-18 final commit with proper silkscreen and pdf exports
    [io-board.kicad_pcb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]
2017-05-20 Add branding
    [io-board.kicad_pcb, main-board.kicad_pcb]
2017-05-23 finished fixes for the board
    [_saved_main-board.sch, main-board.kicad_pcb]
2017-05-23 finished fixes for io-board
    [_saved_main-board.sch, io-board.kicad_pcb, main-board.sch]
2017-05-23 Update gerbers and branding
    [io-board-B.CrtYd.gbr, io-board-B.Cu.gbr, io-board-B.Mask.gbr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]
2017-05-25 added BOM without Digikey part numbers
    [BOM.ods]
2017-05-27 finished BOM
    [BOM.ods, io-board.sch]
2017-05-28 reorganised directories
    [BOM.ods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]
2017-06-27 added gpio pin intialization function
2017-07-03 added SPI functions
2017-07-03 finish implementing SPI abstraction
2017-07-03 added switches.c
2017-07-04 need to write shift register driver first
2017-07-04 partially implemented shift register driver
2017-07-04 finished implementing 75hc595 drivers
2017-07-04 finished with switches
2017-07-05 fixed the switch scanning code
2017-07-10 started work on the i2c abstraction
2017-07-10 implemented driver adapter interface for i2c
2017-07-10 added i2c initialisation code
2017-07-10 finished i2c driver
2017-07-10 added I2C status state machine
2017-07-10 populating the driver code for main-board from io-board
2017-07-11 bodged the hardware board, testing Shift code
    [74hc595.h]
2017-07-16 updated io-board code
2017-07-16 fixing IO board
2017-07-16 figured out problem with DDRx function argument
    [74hc595.c, main.c]
2017-07-16 more problems with Shift reg
    [74hc595.c, main.c]
2017-07-16 problem is within spi
    [74hc595.c, 74hc595.h, main.c]
2017-07-19 switch to no-spi peripheral
2017-07-21 rough I2C implementation
2017-07-21 starting to populate the I2C
2017-07-21 finished up io-board firmware
2017-07-22 wth, tx & rx flipped
    [main-board.sch]
